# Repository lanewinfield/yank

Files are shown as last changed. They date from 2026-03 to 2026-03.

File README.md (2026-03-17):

# ***Yank!***

***Yank!*** is a purposeful way to use your computer.

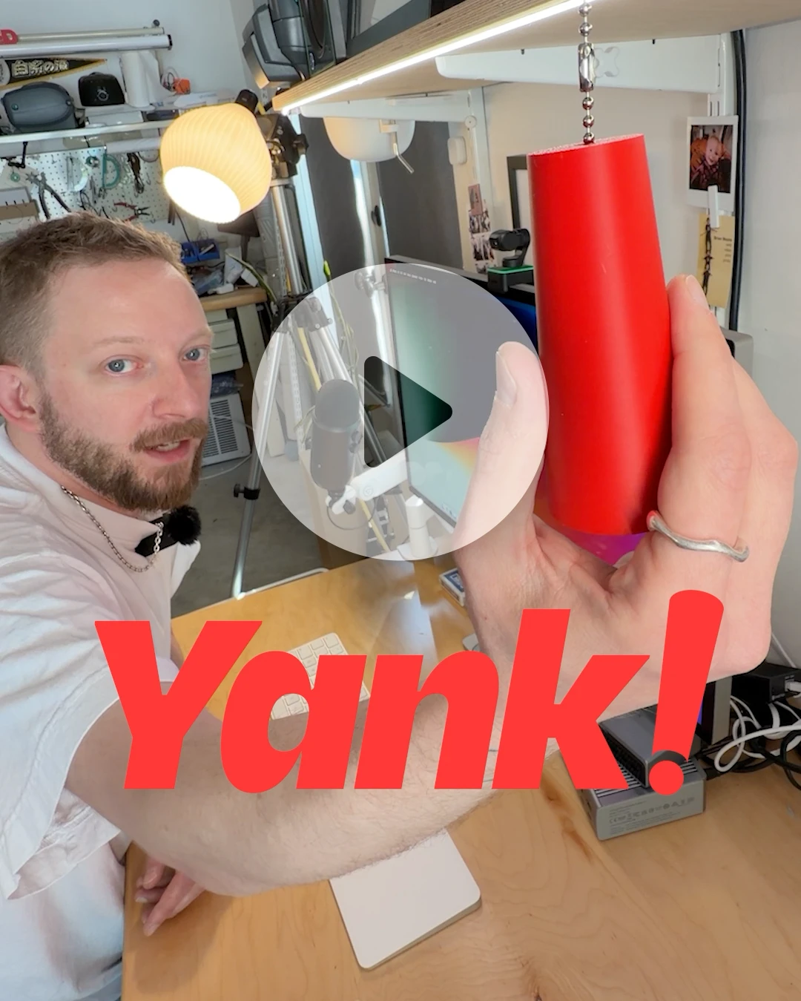
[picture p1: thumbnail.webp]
Watch video


**[Watch video](https://www.instagram.com/p/DV84M5tjh6s/)**

*Disclosure: this video was in partnership with Anthropic.*

## What it does

***Yank!*** is a physical pull switch that connects to your Mac over BLE and triggers configurable actions — play a sound, mute your mic, end a video call, run a script, whatever you want. One pull, instant reaction. More at [yank.computer](https://yank.computer).

## Repo structure

| Folder | Description |
|---|---|
| [`firmware/`](firmware/) | Zephyr/nRF Connect SDK firmware for the XIAO nRF54L15 |
| [`macos-app/`](macos-app/) | ***Yank!*** Companion App — macOS menu bar app (SwiftUI + CoreBluetooth) |
| [`hardware/`](hardware/) | 3D-printable enclosure (STL) and editable model (Fusion) |
| [`website/`](website/) | Landing page at yank.computer |

## Features

- Play a sound
- Play/pause music
- Press key commands
- Mute/unmute audio
- Mute/unmute microphone
- Display a notification
- Run a custom script
- End video calls (Zoom, Meet, FaceTime, Teams)
- Whatever you want (given that you're willing to make it happen!)

## Hardware

| Component | Detail |
|---|---|
| Board | [Seeed XIAO nRF54L15](https://wiki.seeedstudio.com/xiao-nrf54l15/) |
| Switch | [Single Circuit Pull Chain Switch](https://www.homedepot.com/p/Gardner-Bender-3-Amp-Single-Pole-Single-Circuit-Pull-Chain-Switch-Nickel-1-Pack-GSW-31/100126308) (Most companies sell the same exact one) |
| Power | [100mAh LiPo battery](https://www.amazon.com/dp/B0CNLNHK4F?th=1) via XIAO battery connector |

See [`firmware/README.md`](firmware/README.md) for BLE protocol details, pin assignments, and LED patterns.

## Building — Firmware

### Prerequisites

- [nRF Connect SDK v2.9.0](https://developer.nordicsemi.com/nRF_Connect_SDK/doc/latest/nrf/installation.html) installed at `~/ncs`
- `west` meta-tool
- Zephyr SDK toolchain (arm-zephyr-eabi)

### Build & flash

```bash
cd firmware
export ZEPHYR_BASE=~/ncs/zephyr

west build -b xiao_nrf54l15/nrf54l15/cpuapp --build-dir build
```

Flash via UF2: double-press reset, then copy the UF2 to the mounted drive:

```bash
python3 ~/ncs/zephyr/scripts/build/uf2conv.py build/firmware/zephyr/zephyr.hex \
  -c -f 0x00000000 -o yank.uf2
cp yank.uf2 /Volumes/XIAO-SENSE/
```

Or flash via J-Link: `west flash --build-dir build`

## ***Yank!*** Companion App (macOS)

**[Download the latest release (DMG)](https://github.com/lanewinfield/yank/releases/latest)**

### Building from source

#### Prerequisites

- macOS 13.0+
- Xcode 15.0+

#### Build

```bash
cd macos-app
xcodebuild -project YankCompanion.xcodeproj -scheme YankCompanion -configuration Release build
```

The built app lands in `~/Library/Developer/Xcode/DerivedData/YankCompanion-*/Build/Products/Release/Yank Companion.app`.

## License

[CC BY-NC-SA 4.0](LICENSE) — free to use and remix with attribution, non-commercial, share-alike.

---

Made by [Brian Moore](https://brianmoore.com) (w/ plenty of assist from [Claude](https://claude.ai))

*Disclosure: the [video](https://www.instagram.com/p/DV84M5tjh6s/) featured in this README was made in partnership with Anthropic.*

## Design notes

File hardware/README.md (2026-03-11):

# ***Yank!*** Hardware

3D-printable enclosure for the ***Yank!*** pull switch.

## Files

### 3D Print Files (STL)

| File | Description |
|---|---|
| `yank-outer-shell.stl` | Outer shell of the enclosure |
| `yank-internal-top-half.stl` | Internal top half (holds the switch) |
| `yank-internal-bottom-half.stl` | Internal bottom half (holds the microcontroller) |

### 3D Models (Editable)

| File | Description |
|---|---|
| `yank-enclosure.f3d` | Full enclosure model (Autodesk Fusion) |

## Print settings

Printed on a Bambu Lab P1S with default settings and supports enabled. No special tuning required.

The battery is sandwiched between the two internal halves.

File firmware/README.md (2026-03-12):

# ***Yank!*** Firmware

BLE firmware for the ***Yank!*** pull switch device, built on the Seeed XIAO nRF54L15 using the nRF Connect SDK (Zephyr RTOS).

## Hardware

| Component | Detail |
|---|---|
| Board | Seeed XIAO nRF54L15 |
| MCU | Nordic nRF54L15, ARM Cortex-M33 |
| Pull Switch | Momentary, wired to **D3** (gpio1 pin 7) |
| Power | LiPo battery via XIAO battery connector |
| LED | On-board LED0 (gpio2 pin 0) used for status |

### Pin Assignments

| Pin | Function | GPIO | Config |
|-----|---|---|---|
| D3 | Pull switch input | gpio1.7 | Internal pull-up, active low |
| LED0 | Status indicator | gpio2.0 | Active low |

## BLE Protocol

### Device Name
The device advertises as **"Yank!"**

### Service: ***Yank!*** Pull Service

| Field | Value |
|---|---|
| Service UUID | `b26f59c7-68f1-48c8-a4d1-676648080123` |

### Characteristic: Pull Event

| Field | Value |
|---|---|
| UUID | `b26f59c7-68f1-48c8-a4d1-676648080124` |
| Properties | Notify only |
| Data format | 2 bytes: `[pull_count, elapsed_ds]` |

**Data format details:**

| Byte | Name | Description |
|---|---|---|
| 0 | `pull_count` | Monotonically increasing counter (1–255, wraps around, never 0). Use to detect missed events. |
| 1 | `elapsed_ds` | Deciseconds (tenths of a second) since the previous pull. 0 on first pull. Capped at 255 (25.5s). |

### Service: Battery (Standard BLE)

| Field | Value |
|---|---|
| Service UUID | `0x180F` (standard Battery Service) |
| Characteristic UUID | `0x2A19` (Battery Level) |
| Data format | 1 byte: 0–100 (percent) |

Battery level is measured every 5 minutes via the SAADC and reported through the standard BLE Battery Service.

### Advertising Data

The device advertises with:
- **Flags:** General Discoverable + BR/EDR Not Supported
- **Complete Local Name:** "Yank!"
- **Scan Response:** 128-bit Service UUID list containing `b26f59c7-68f1-48c8-a4d1-676648080123`

### Connection Parameters

| Parameter | Value |
|---|---|
| Min interval | 7.5 ms (6 × 1.25 ms) |
| Max interval | 30 ms (24 × 1.25 ms) |
| Latency | 4 |
| Supervision timeout | 4000 ms |

These values balance responsiveness with power efficiency. The Mac app should accept these parameters.

## Reset Procedures

Since the device is fully enclosed with no access to the reset button, firmware resets are triggered via rapid successive pulls:

| Gesture | Action |
|---|---|
| **5 pulls within 2 seconds** | **Soft reset** — restarts the firmware (warm reboot) |
| **8 pulls within 3 seconds** | **Factory reset** — clears all bonding/pairing data, then cold reboots |

The LED provides visual feedback:
- **Soft reset:** 5 slow blinks (100ms on/off) before reboot
- **Factory reset:** 10 rapid blinks (50ms on/off) before reboot

## LED Indications

| Pattern | Meaning |
|---|---|
| 2 short blinks on startup | Firmware ready |
| 1 short blink | BLE connection established |
| 3 rapid blinks | BLE disconnected |
| 5 slow blinks | Soft reset in progress |
| 10 rapid blinks | Factory reset in progress |

## Building

### Prerequisites

- [nRF Connect SDK v2.9.0](https://developer.nordicsemi.com/nRF_Connect_SDK/doc/latest/nrf/installation.html) installed at `~/ncs`
- `west` meta-tool
- Zephyr SDK toolchain (arm-zephyr-eabi)

### Build Commands

```bash
cd firmware

# Set Zephyr base (if not already in environment)
export ZEPHYR_BASE=~/ncs/zephyr

# Build
west build -b xiao_nrf54l15/nrf54l15/cpuapp --build-dir build

# Clean rebuild
rm -rf build && west build -b xiao_nrf54l15/nrf54l15/cpuapp --build-dir build
```

The build output is at `build/firmware/zephyr/zephyr.hex` (merged output at `build/merged.hex`).

## Flashing

### Via USB (UF2 bootloader)

1. Connect XIAO nRF54L15 via USB
2. Double-press the reset button to enter UF2 bootloader mode
3. A USB drive named "XIAO-SENSE" will appear
4. Copy the UF2 file to the drive:

```bash
# Convert hex to UF2 if needed
python3 ~/ncs/zephyr/scripts/build/uf2conv.py build/firmware/zephyr/zephyr.hex -c -f 0x00000000 -o yank.uf2
cp yank.uf2 /Volumes/XIAO-SENSE/
```

### Via J-Link / SWD

```bash
west flash --build-dir build
```

### Via nrfjprog

```bash
nrfjprog --program build/merged.hex --sectorerase --verify --reset
```

## Full Device Reset (Mass Erase)

If the device gets into a bad state (e.g. `bt_enable()` hangs and BLE never starts), a mass erase via the CTRL-AP will wipe all flash and RRAM and fully reset the SoC — the closest thing to a power cycle without removing the battery.

```bash
openocd \
  -f ~/ncs/zephyr/boards/seeed/xiao_nrf54l15/support/openocd.cfg \
  -c "init; nrf54l_mass_erase; shutdown"
```

After the erase, reflash the firmware:

```bash
west flash -d /path/to/firmware/build/firmware
```

## Debugging (RTT Console)

The XIAO nRF54L15's USB port is a CMSIS-DAP debug probe only — UART is not routed through USB. To view console output, use Segger RTT (Real-Time Transfer) which reads directly through the debug probe.

### 1. Enable RTT in `prj.conf`

Change the serial/console section to:

```
CONFIG_SERIAL=n
CONFIG_CONSOLE=y
CONFIG_UART_CONSOLE=n
CONFIG_USE_SEGGER_RTT=y
CONFIG_RTT_CONSOLE=y
```

### 2. Rebuild and flash

```bash
cd ~/ncs
west build -b xiao_nrf54l15/nrf54l15/cpuapp /path/to/firmware --build-dir /path/to/firmware/build --pristine
west flash -d /path/to/firmware/build/firmware
```

Note: `west flash` needs the `build/firmware` subdirectory (not just `build`) due to the sysbuild structure.

### 3. Read RTT output via OpenOCD

```bash
# Start OpenOCD with RTT server
openocd \
  -f /path/to/ncs/zephyr/boards/seeed/xiao_nrf54l15/support/openocd.cfg \
  -c "init; rtt setup 0x20000000 0x10000 \"SEGGER RTT\"; rtt start; rtt server start 9090 0"

# In another terminal, connect to the RTT stream
nc localhost 9090
```

To reset the device while reading RTT, connect to the OpenOCD telnet interface and issue a reset:

```bash
# In a third terminal
nc localhost 4444
> reset run
```

### 4. Revert to production mode

Change `prj.conf` back to disable serial/RTT for battery savings (~1-2mA):

```
CONFIG_SERIAL=n
CONFIG_CONSOLE=n
CONFIG_UART_CONSOLE=n
```

Rebuild and flash again.

## Behavior

### Normal Operation
1. On power-up, firmware initializes BLE and begins advertising as "Yank!"
2. The Mac companion app discovers and connects to the device
3. Each pull of the switch sends a BLE notification to the connected app
4. When idle, the MCU enters low-power sleep automatically (Zephyr PM)

### Disconnected Behavior
- When the BLE connection drops, the device automatically restarts advertising
- A single pull while disconnected also triggers advertising for reconnection
- The device remembers bonded devices and will reconnect automatically

### Power Management
- Zephyr's built-in power management puts the CPU to sleep between events
- GPIO interrupt wakes the CPU instantly on pull switch activation
- BLE connection is maintained during sleep via the SoftDevice controller
- Battery level is measured every 5 minutes

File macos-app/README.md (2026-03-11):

# ***Yank!*** Companion App

A menu bar app that connects to the ***Yank!*** BLE pull switch device and executes configurable actions when the switch is pulled.

## Building

### Prerequisites
- macOS 13.0+
- Xcode 15.0+ (with command line tools)

### Build from CLI

```bash
cd macos-app
xcodebuild -project YankCompanion.xcodeproj -scheme YankCompanion -configuration Debug build
```

The built app will be in `~/Library/Developer/Xcode/DerivedData/YankCompanion-*/Build/Products/Debug/Yank Companion.app`.

### Build Release

```bash
xcodebuild -project YankCompanion.xcodeproj -scheme YankCompanion -configuration Release build
```

## Usage

1. **Launch** - The app runs as a menu bar-only app (no dock icon). Look for the switch icon in the menu bar.
2. **Connect** - The app automatically scans for a ***Yank!*** BLE device. Make sure your device is powered on.
3. **Configure Actions** - Click the menu bar icon and use "Add Action" to configure what happens on each pull.
4. **Test** - Use the "Test" button to simulate a pull event without the physical device.

## Available Actions

| Action | SF Symbol | Multiple Allowed |
|---|---|---|
| Play a Sound | speaker.wave.2 | Yes |
| Play/Pause Music | playpause | No |
| Press Key Command | keyboard | No |
| Display Notification | bell | No |
| Mute/Unmute Audio | speaker.slash | No |
| Mute/Unmute Mic | mic.slash | No |
| Run Custom Script | terminal | Yes |
| End Video Calls | video.slash | No |

## Permissions

- **Bluetooth** - Required for BLE connection to the ***Yank!*** device
- **Accessibility** - Required for "Press Key Command" action (simulating keystrokes)
- **Automation** - Required for "End Video Calls" action (controlling other apps via AppleScript)

## BLE Protocol

The app connects to a device advertising as "Yank!" with:
- Service UUID: `b26f59c7-68f1-48c8-a4d1-676648080123`
- Pull Event Characteristic UUID: `b26f59c7-68f1-48c8-a4d1-676648080124`
  - Notify only, 2-byte payload: `[pull_count, elapsed_ds]`
- Battery: Standard BLE Battery Service (0x180F / 0x2A19)

## Project Structure

```
macos-app/
├── YankCompanion.xcodeproj/
│   └── project.pbxproj
├── YankCompanion/
│   ├── YankCompanionApp.swift      # App entry point
│   ├── AppDelegate.swift           # Menu bar setup, BLE + action wiring
│   ├── Info.plist                  # App config (LSUIElement, BT usage)
│   ├── YankCompanion.entitlements  # Permissions
│   ├── Models/
│   │   ├── YankAction.swift        # Action type definitions
│   │   └── ActionStore.swift       # Persistence (UserDefaults)
│   ├── BLE/
│   │   └── BLEManager.swift        # CoreBluetooth scanning/connection
│   ├── Actions/
│   │   └── ActionExecutor.swift    # Action execution logic
│   ├── Views/
│   │   ├── ContentView.swift       # Main popover view
│   │   ├── ActionRowView.swift     # Individual action row
│   │   ├── AddActionView.swift     # Action type picker + config
│   │   ├── OnboardingView.swift    # First-launch walkthrough
│   │   └── HUDNotification.swift   # macOS-style HUD overlay
│   └── Resources/
│       ├── pull-switch.mp3         # Pull switch sound
│       ├── boom.wav                # Bundled sound
│       ├── fart.wav                # Bundled sound
│       ├── toilet.wav              # Bundled sound
│       └── whistle.wav             # Bundled sound
└── README.md
```

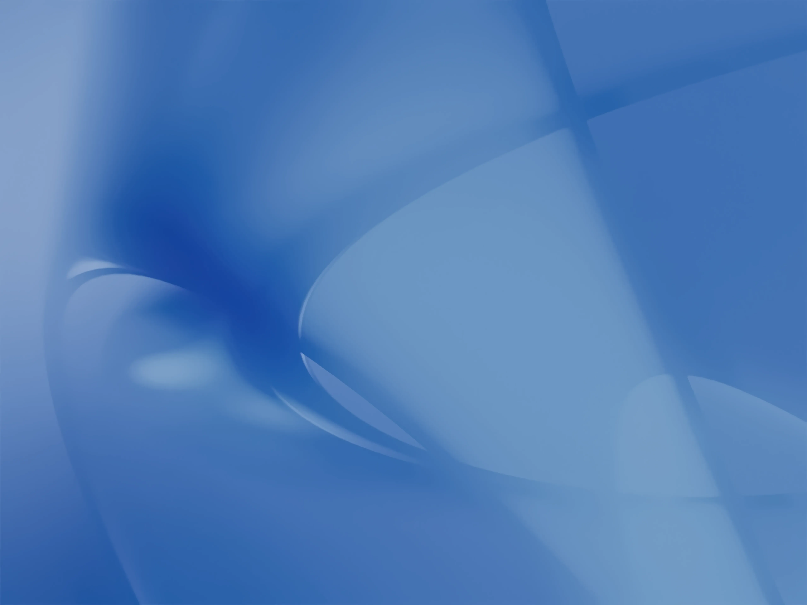
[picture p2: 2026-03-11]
website/assets/images/wallpaper.webp

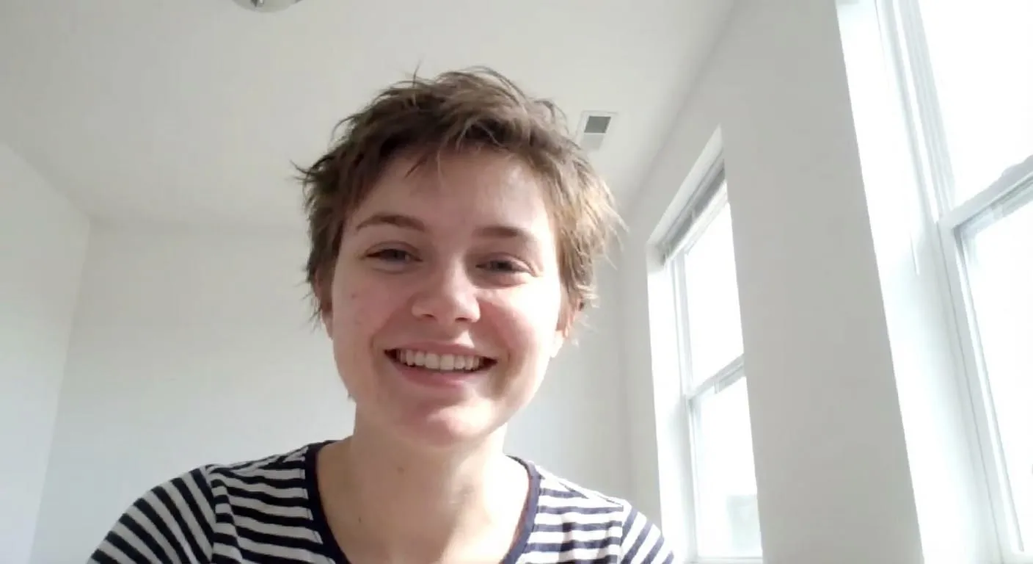
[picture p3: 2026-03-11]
website/assets/images/portraits/IMAGE 2026-02-06 11:04:18.webp

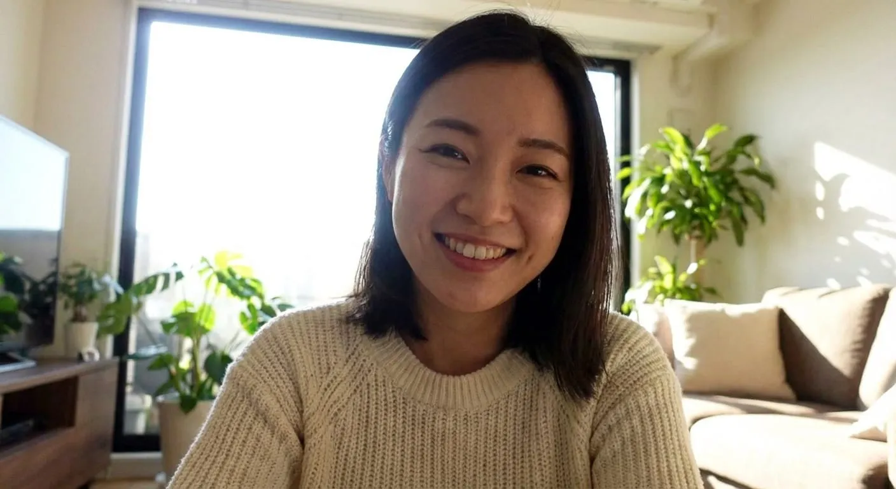
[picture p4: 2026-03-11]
website/assets/images/portraits/IMAGE 2026-02-05 15:35:34.webp

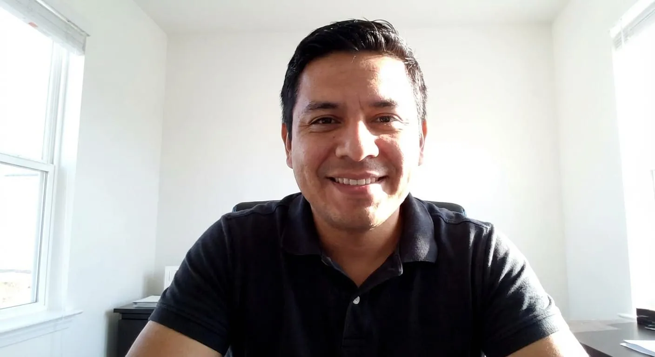
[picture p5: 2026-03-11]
website/assets/images/portraits/IMAGE 2026-02-05 15:35:35.webp

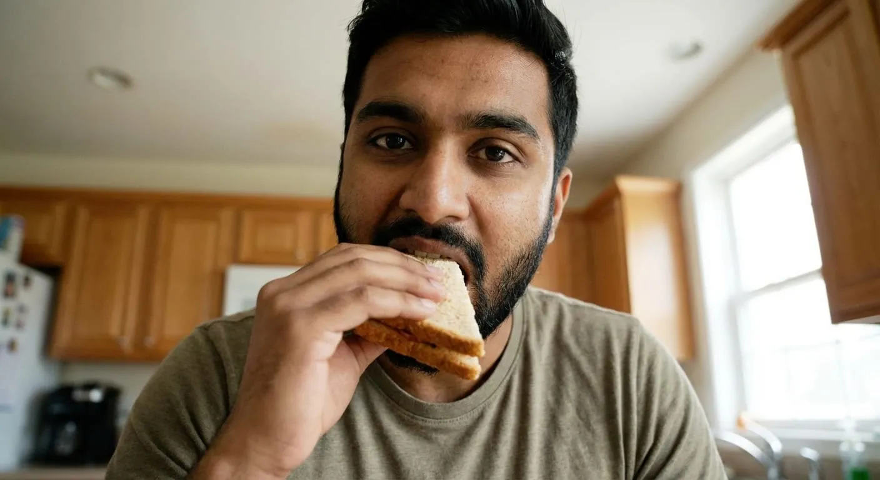
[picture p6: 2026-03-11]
website/assets/images/portraits/IMAGE 2026-02-06 11:16:56.webp

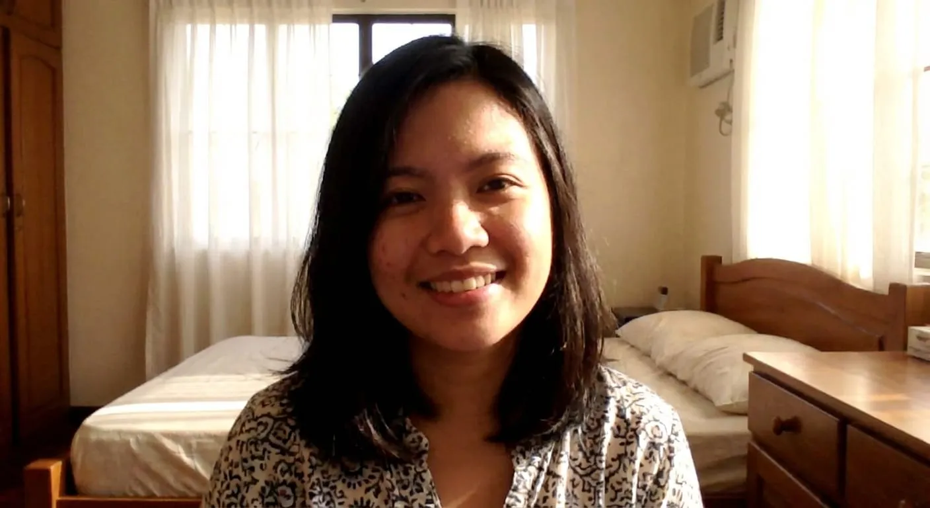
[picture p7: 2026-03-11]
website/assets/images/portraits/IMAGE 2026-02-06 11:04:20.webp

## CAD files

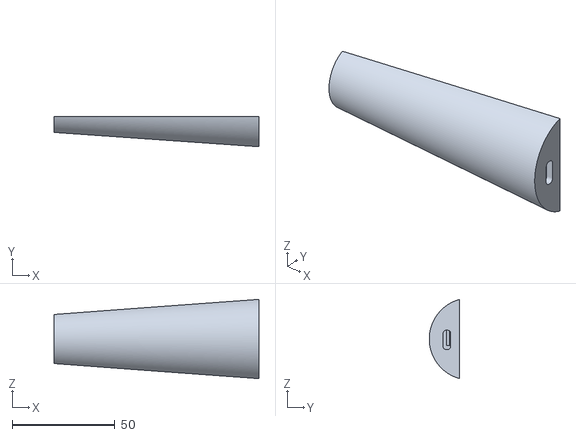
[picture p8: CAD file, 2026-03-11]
hardware/3D Print Files/yank-internal-bottom-half.stl
100.0 x 14.9 x 38.7

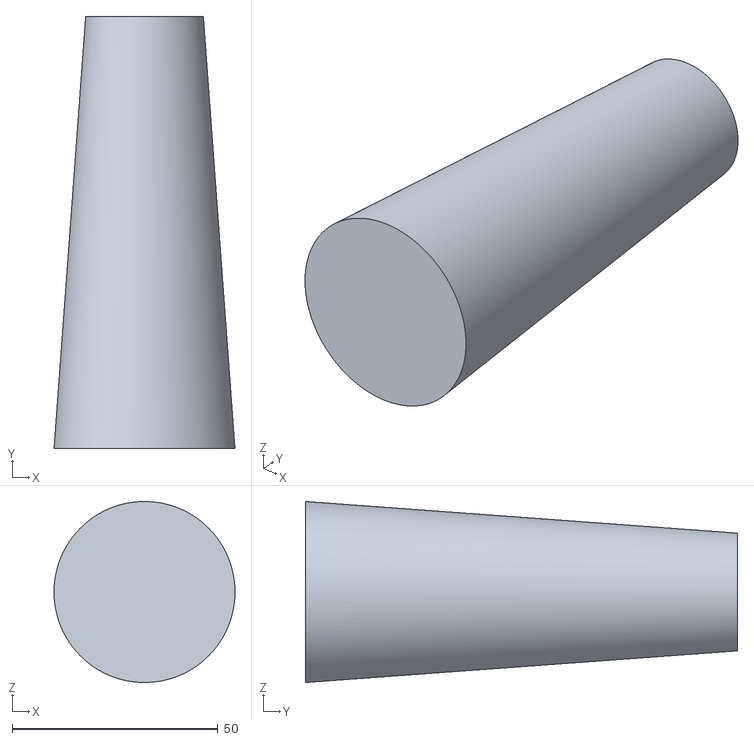
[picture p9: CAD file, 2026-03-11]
website/assets/models/handle.stl
44.0 x 105.0 x 44.0

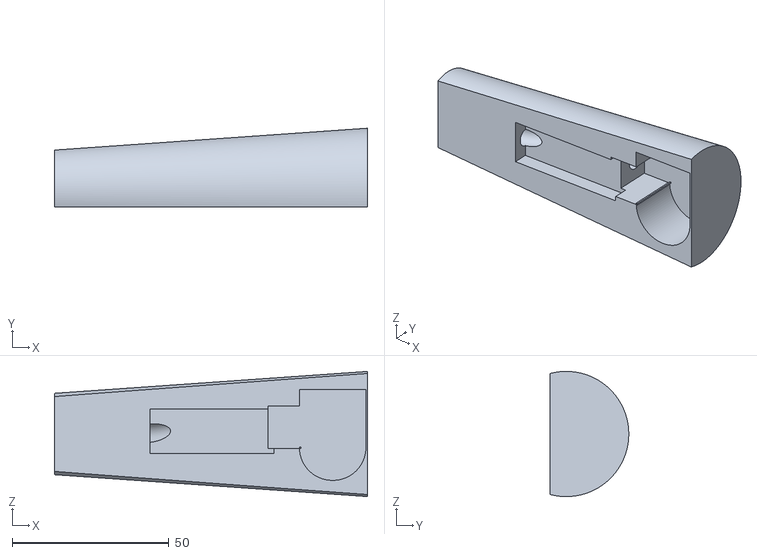
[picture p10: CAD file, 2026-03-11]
hardware/3D Print Files/yank-internal-top-half.stl
100.0 x 25.1 x 40.0

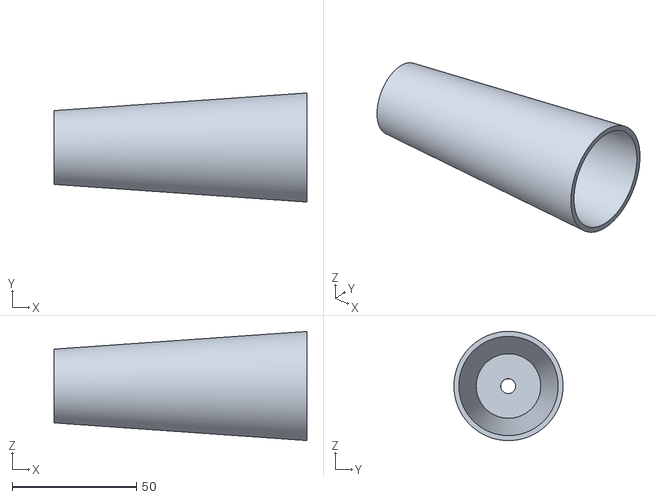
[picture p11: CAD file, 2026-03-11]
hardware/3D Print Files/yank-outer-shell.stl
102.0 x 44.0 x 44.0

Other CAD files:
hardware/3D Models/yank-enclosure.f3d

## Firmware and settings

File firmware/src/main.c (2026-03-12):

/*
 * Yank! Pull Switch Firmware
 *
 * Hardware: Seeed XIAO nRF54L15
 * Pull switch on D3 (gpio1 pin 7), active low with internal pull-up.
 *
 * Power strategy:
 *   - CONFIG_PM=y lets the CPU sleep between events (System ON idle)
 *   - GPIO interrupt wakes CPU instantly on pull
 *   - Relaxed BLE connection interval (30-50ms) with slave latency 4
 *   - On pull: request fast interval (7.5-15ms) for reliable delivery,
 *     then relax back after 2 seconds
 *   - Advertising slows down after 30s of no connection
 *   - Battery read every 60s instead of 30s
 *   - UART disabled in production build
 */

#include <zephyr/kernel.h>
#include <zephyr/drivers/gpio.h>
#include <zephyr/bluetooth/bluetooth.h>
#include <zephyr/bluetooth/conn.h>
#include <zephyr/bluetooth/gatt.h>
#include <zephyr/bluetooth/uuid.h>
#include <zephyr/bluetooth/services/bas.h>
#include <zephyr/drivers/adc.h>
#include <zephyr/sys/printk.h>

/* ── UUIDs ─────────────────────────────────────────────── */

#define BT_UUID_YANK_SVC_VAL \
	BT_UUID_128_ENCODE(0xb26f59c7, 0x68f1, 0x48c8, 0xa4d1, 0x676648080123)
#define BT_UUID_YANK_SVC    BT_UUID_DECLARE_128(BT_UUID_YANK_SVC_VAL)

#define BT_UUID_YANK_PULL_VAL \
	BT_UUID_128_ENCODE(0xb26f59c7, 0x68f1, 0x48c8, 0xa4d1, 0x676648080124)
#define BT_UUID_YANK_PULL   BT_UUID_DECLARE_128(BT_UUID_YANK_PULL_VAL)

/* ── Connection parameter profiles ─────────────────────── */

/* Fast: used briefly after a pull for reliable notification delivery */
static const struct bt_le_conn_param conn_param_fast =
	BT_LE_CONN_PARAM_INIT(6, 12, 0, 400);   /* 7.5-15ms, no latency */

/* Idle: relaxed for power savings. Latency 4 = radio skips 4 events. */
static const struct bt_le_conn_param conn_param_idle =
	BT_LE_CONN_PARAM_INIT(24, 40, 4, 400);  /* 30-50ms, latency 4 */

/* ── Hardware ──────────────────────────────────────────── */

static const struct gpio_dt_spec pull_switch =
	GPIO_DT_SPEC_GET(DT_ALIAS(yank_switch), gpios);

static const struct gpio_dt_spec led =
	GPIO_DT_SPEC_GET(DT_ALIAS(led0), gpios);

/* ── BLE state ─────────────────────────────────────────── */

static bool notify_enabled;
static bool is_connected;
static bool is_advertising;
static uint8_t pull_count;
static struct bt_conn *current_conn;

/* ── GATT service ──────────────────────────────────────── */

static void ccc_changed(const struct bt_gatt_attr *attr, uint16_t value)
{
	notify_enabled = (value == BT_GATT_CCC_NOTIFY);
	printk("Notifications %s\n", notify_enabled ? "on" : "off");
}

BT_GATT_SERVICE_DEFINE(yank_svc,
	BT_GATT_PRIMARY_SERVICE(BT_UUID_YANK_SVC),
	BT_GATT_CHARACTERISTIC(BT_UUID_YANK_PULL,
		BT_GATT_CHRC_NOTIFY,
		BT_GATT_PERM_NONE,
		NULL, NULL, NULL),
	BT_GATT_CCC(ccc_changed,
		BT_GATT_PERM_READ | BT_GATT_PERM_WRITE),
);

/* ── Connection parameter management ──────────────────── */

static struct k_work_delayable relax_conn_work;

static void relax_conn_handler(struct k_work *work)
{
	if (current_conn) {
		bt_conn_le_param_update(current_conn, &conn_param_idle);
		printk("Conn params -> idle\n");
	}
}

static void request_fast_conn(void)
{
	if (!current_conn) {
		return;
	}
	bt_conn_le_param_update(current_conn, &conn_param_fast);
	printk("Conn params -> fast\n");

	/* Relax back to idle after 2 seconds */
	k_work_reschedule(&relax_conn_work, K_SECONDS(2));
}

/* ── Notification ──────────────────────────────────────── */

static int64_t last_pull_time;

static void send_pull_notification(void)
{
	if (!is_connected || !notify_enabled) {
		return;
	}

	/* Switch to fast connection interval for reliable delivery */
	request_fast_conn();

	pull_count++;
	if (pull_count == 0) {
		pull_count = 1;
	}

	int64_t now = k_uptime_get();
	uint8_t elapsed_ds = 0;
	if (last_pull_time > 0) {
		int64_t ds = (now - last_pull_time) / 100;
		elapsed_ds = (ds > 255) ? 255 : (uint8_t)ds;
	}
	last_pull_time = now;

	uint8_t data[2] = { pull_count, elapsed_ds };
	bt_gatt_notify(NULL, &yank_svc.attrs[1], data, sizeof(data));
}

/* ── Advertising ───────────────────────────────────────── */

#define DEVICE_NAME     CONFIG_BT_DEVICE_NAME
#define DEVICE_NAME_LEN (sizeof(DEVICE_NAME) - 1)

static const struct bt_data ad[] = {
	BT_DATA_BYTES(BT_DATA_FLAGS, (BT_LE_AD_GENERAL | BT_LE_AD_NO_BREDR)),
	BT_DATA(BT_DATA_NAME_COMPLETE, DEVICE_NAME, DEVICE_NAME_LEN),
};

static const struct bt_data sd[] = {
	BT_DATA_BYTES(BT_DATA_UUID128_ALL, BT_UUID_YANK_SVC_VAL),
};

/* Fast advertising for initial 30s, then slow down */
static struct k_work_delayable slow_adv_work;

/* Fast: 100ms interval. Slow: 1s interval. */
#define ADV_FAST_PARAMS BT_LE_ADV_PARAM(BT_LE_ADV_OPT_CONNECTABLE, \
	BT_GAP_ADV_FAST_INT_MIN_2, BT_GAP_ADV_FAST_INT_MAX_2, NULL)

#define ADV_SLOW_PARAMS BT_LE_ADV_PARAM(BT_LE_ADV_OPT_CONNECTABLE, \
	0x0640, 0x0640, NULL)  /* 1000ms */

static void start_advertising_with_params(const struct bt_le_adv_param *params)
{
	if (is_advertising) {
		bt_le_adv_stop();
		is_advertising = false;
	}
	int err = bt_le_adv_start(params, ad, ARRAY_SIZE(ad),
				  sd, ARRAY_SIZE(sd));
	if (err) {
		printk("Adv failed (%d)\n", err);
		return;
	}
	is_advertising = true;
}

static void slow_adv_handler(struct k_work *work)
{
	if (is_advertising && !is_connected) {
		printk("Adv -> slow\n");
		start_advertising_with_params(ADV_SLOW_PARAMS);
	}
}

static void start_advertising(void)
{
	start_advertising_with_params(ADV_FAST_PARAMS);
	/* Switch to slow advertising after 30 seconds */
	k_work_schedule(&slow_adv_work, K_SECONDS(30));
}

/* ── Connection callbacks ──────────────────────────────── */

static void connected_cb(struct bt_conn *conn, uint8_t err)
{
	if (err) {
		printk("Connect failed (0x%02x)\n", err);
		return;
	}
	printk("Connected\n");
	current_conn = bt_conn_ref(conn);
	is_connected = true;
	is_advertising = false;
	gpio_pin_set_dt(&led, 1);

	/* Cancel slow-adv timer */
	k_work_cancel_delayable(&slow_adv_work);
}

static void disconnected_cb(struct bt_conn *conn, uint8_t reason)
{
	printk("Disconnected (0x%02x)\n", reason);
	if (current_conn) {
		bt_conn_unref(current_conn);
		current_conn = NULL;
	}
	is_connected = false;
	notify_enabled = false;
	gpio_pin_set_dt(&led, 0);

	/* Cancel any pending relax timer */
	k_work_cancel_delayable(&relax_conn_work);

	start_advertising();
}

BT_CONN_CB_DEFINE(conn_cbs) = {
	.connected = connected_cb,
	.disconnected = disconnected_cb,
};

/* ── Pull switch handling (trailing-edge debounce) ─────── */

static struct k_work_delayable debounce_work;
static struct gpio_callback switch_cb_data;
static volatile bool pull_pending;

static void debounce_handler(struct k_work *work)
{
	if (pull_pending) {
		pull_pending = false;
		printk("Pull!\n");
		send_pull_notification();

		if (!is_connected) {
			start_advertising();
		}
	}
}

static void switch_isr(const struct device *dev, struct gpio_callback *cb,
		       uint32_t pins)
{
	pull_pending = true;
	/* Reset the 50ms timer on every bounce edge */
	k_work_reschedule(&debounce_work, K_MSEC(50));
}

/* ── Battery ───────────────────────────────────────────── */

static const struct adc_dt_spec adc_chan =
	ADC_DT_SPEC_GET_BY_IDX(DT_PATH(zephyr_user), 0);

static bool adc_ready;
static int16_t adc_buf;
static struct k_work_delayable battery_work;

#define BATTERY_READ_INTERVAL_S 60

static void battery_work_handler(struct k_work *work)
{
	if (!adc_ready) {
		goto resched;
	}

	struct adc_sequence seq = {
		.buffer = &adc_buf,
		.buffer_size = sizeof(adc_buf),
		.channels = BIT(adc_chan.channel_id),
		.resolution = 12,
	};

	if (adc_read(adc_chan.dev, &seq) < 0) {
		goto resched;
	}

	int32_t mv = adc_buf;
	adc_raw_to_millivolts_dt(&adc_chan, &mv);

	/* 2:1 voltage divider on board */
	mv *= 2;

	uint8_t pct;
	if (mv >= 4200) {
		pct = 100;
	} else if (mv <= 3300) {
		pct = 0;
	} else {
		pct = (uint8_t)(((mv - 3300) * 100) / 900);
	}

	bt_bas_set_battery_level(pct);
	printk("Battery: %d mV -> %d%%\n", mv, pct);

resched:
	k_work_schedule(&battery_work, K_SECONDS(BATTERY_READ_INTERVAL_S));
}

static void init_adc(void)
{
	if (!adc_is_ready_dt(&adc_chan)) {
		printk("ADC not ready\n");
		return;
	}
	if (adc_channel_setup_dt(&adc_chan) < 0) {
		printk("ADC channel setup failed\n");
		return;
	}
	adc_ready = true;
}

/* ── Main ──────────────────────────────────────────────── */

int main(void)
{
	/* Brief delay to let HFXO stabilize before radio init.
	 * Some nRF54L15 units need this when UART/console is disabled
	 * (the UART init normally provides enough startup time). */
	k_msleep(100);

	int err = bt_enable(NULL);
	if (err) {
		return err;
	}

	/* LED */
	if (gpio_is_ready_dt(&led)) {
		gpio_pin_configure_dt(&led, GPIO_OUTPUT_INACTIVE);
	}

	/* Pull switch */
	gpio_pin_configure_dt(&pull_switch, GPIO_INPUT);
	gpio_pin_interrupt_configure_dt(&pull_switch, GPIO_INT_EDGE_BOTH);
	gpio_init_callback(&switch_cb_data, switch_isr, BIT(pull_switch.pin));
	gpio_add_callback(pull_switch.port, &switch_cb_data);
	k_work_init_delayable(&debounce_work, debounce_handler);

	/* Connection parameter management */
	k_work_init_delayable(&relax_conn_work, relax_conn_handler);

	/* Advertising slow-down timer */
	k_work_init_delayable(&slow_adv_work, slow_adv_handler);

	/* Battery ADC */
	init_adc();
	k_work_init_delayable(&battery_work, battery_work_handler);

	start_advertising();
	k_work_schedule(&battery_work, K_SECONDS(5));

	return 0;
}

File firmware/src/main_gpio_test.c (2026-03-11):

/*
 * GPIO interrupt test — trailing-edge debounce.
 * Wait for 50ms of no bouncing, then count as one pull.
 */

#include <zephyr/kernel.h>
#include <zephyr/drivers/gpio.h>
#include <zephyr/sys/printk.h>

static const struct gpio_dt_spec pull_switch =
	GPIO_DT_SPEC_GET(DT_ALIAS(yank_switch), gpios);

static struct gpio_callback switch_cb_data;
static struct k_work_delayable debounce_work;
static volatile uint32_t pull_count;
static volatile uint32_t isr_count;
static volatile bool pull_pending;

static void debounce_handler(struct k_work *work)
{
	/* Bouncing has stopped for 50ms — count this as one pull */
	if (pull_pending) {
		pull_pending = false;
		pull_count++;
		printk("Pull #%u (isr_total=%u)\n", pull_count, isr_count);
	}
}

static void switch_isr(const struct device *dev, struct gpio_callback *cb,
		       uint32_t pins)
{
	isr_count++;
	pull_pending = true;
	/* Reset the 50ms timer on every bounce */
	k_work_reschedule(&debounce_work, K_MSEC(50));
}

int main(void)
{
	printk("=== GPIO test (trailing debounce) ===\n");

	gpio_pin_configure_dt(&pull_switch, GPIO_INPUT);
	gpio_pin_interrupt_configure_dt(&pull_switch, GPIO_INT_EDGE_BOTH);
	gpio_init_callback(&switch_cb_data, switch_isr, BIT(pull_switch.pin));
	gpio_add_callback(pull_switch.port, &switch_cb_data);
	k_work_init_delayable(&debounce_work, debounce_handler);

	printk("Ready — pull the switch!\n");

	while (1) {
		k_msleep(1000);
	}
	return 0;
}

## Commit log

2026-03-12 Fix bt_enable() hang on production builds (HFXO timing)
    Add 100ms delay before bt_enable() to let the HFXO crystal stabilize
    when UART/console is disabled. Some nRF54L15 units have slower crystal
    startup and need this when the UART driver init (which normally provides
    enough delay) is removed in production builds.
    Also adds mass erase and RTT debugging documentation to firmware README.
    [main.c]
2026-03-12 Remove handle.stl
    [handle.stl]
